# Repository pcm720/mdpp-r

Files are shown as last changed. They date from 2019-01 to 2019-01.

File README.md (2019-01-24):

## MegaDrive++ R

**MegaDrive++ R** is a modchip for the **Sega Mega Drive/Genesis** heavily inspired by [MegaDrive++ project](https://github.com/SukkoPera/MegaDrivePlusPlus/).
It uses cheap ATmega88PA microcontroller, [cheap PCB](https://oshpark.com/shared_projects/NskgzQ7B) and supports following features:
- **Region switching**: allows user to switch regions with a button combination on Player 1 controller or Reset button.
  - Hold **Left + Start + A** for two seconds to change region to USA, **Left + Start + B** to change region to Europe, and **Left + Start + C** to change region to Japan.
  - Hold **Right** instead of **Left** to change region **and** reset the console.
  - Hold **Left + Start + A + B + C** to save current region to memory and use it as default every time you turn on your console.
  - Hold the **Reset** button for more than four seconds to cycle through modes. This will reset the console.
  - Button combos can be customized in common.h.
- **In-game Reset**: hold **Start + A + B + C** to reset the console.
- Dual-frequency oscillator support: PCB has a special pin for DFO control.
- Unlike [MegaDrive++](https://github.com/SukkoPera/MegaDrivePlusPlus/), it doesn't support reset level autosensing, so to use it on boards with active-high reset signal you'll need to comment out a line in common.h. Note that this is untested: I don't own any consoles with active-high reset.
- Suggested PCB layout is optimized for Model 2 VA1 board.

Visit [wiki](https://github.com/pcm720/mdpp-r/wiki) for installation diagram for Model 2 VA1 board.

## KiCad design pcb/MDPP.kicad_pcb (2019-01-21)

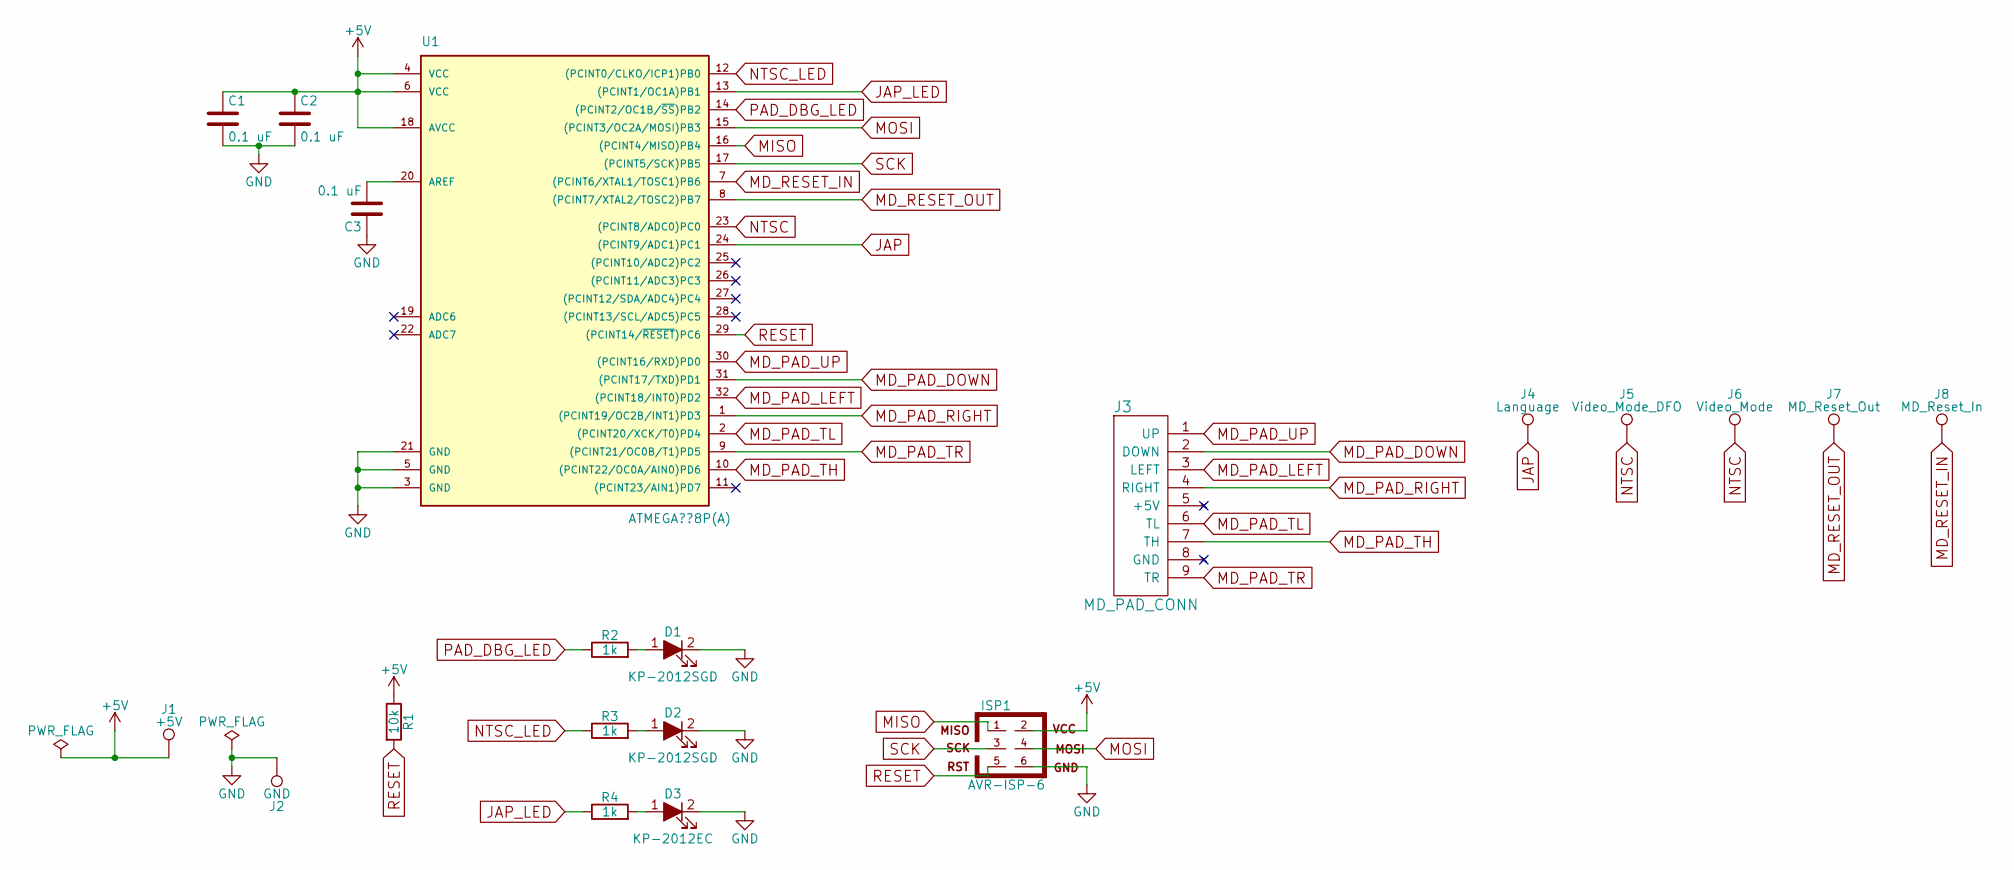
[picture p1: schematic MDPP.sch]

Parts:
D1, D2: KP-2012SGD
D3: KP-2012EC; KP-2012SGD
ISP1: AVR-ISP-6; AVR-ISP-6-SMD
J1: +5V; Soldering_Point_1.5x3mm
J2: GND; Soldering_Point_1.5x3mm
J3: MD_PAD_CONN
J4: Language; Soldering_Point_1.5x3mm
J5: Video_Mode_DFO; Soldering_Point_1.5x3mm
J6: Video_Mode; Soldering_Point_1.5x3mm
J7: MD_Reset_Out; Soldering_Point_1.5x3mm
J8: MD_Reset_In; Soldering_Point_1.5x3mm
R1: 10k; R_0805_HandSoldering
R2, R3, R4: 1k; C_0805
U1: ATMEGA??8P(A); TQFP-32_7x7mm_Pitch0.8mm
С1, С2, С3: 0.1 uF; C_0603_HandSoldering

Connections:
+5V: ISP1.2, J1.1, R1.1, U1.4 (VCC), U1.6 (VCC), U1.18 (AVCC), С1.1, С2.1
GND: D1.2 (A), D2.2 (A), D3.2 (A), ISP1.6, J2.1, U1.3 (GND), U1.5 (GND), U1.21 (GND), С1.2, С2.2, С3.1
JAP: J4.1, U1.24 ((PCINT9/ADC1)PC1)
JAP_LED: R4.1, U1.13 ((PCINT1/OC1A)PB1)
MD_PAD_DOWN: J3.2 (DOWN), U1.31 ((PCINT17/TXD)PD1)
MD_PAD_LEFT: J3.3 (LEFT), U1.32 ((PCINT18/INT0)PD2)
MD_PAD_RIGHT: J3.4 (RIGHT), U1.1 ((PCINT19/OC2B/INT1)PD3)
MD_PAD_TH: J3.7 (TH), U1.10 ((PCINT22/OC0A/AIN0)PD6)
MD_PAD_TL: J3.6 (TL), U1.2 ((PCINT20/XCK/T0)PD4)
MD_PAD_TR: J3.9 (TR), U1.9 ((PCINT21/OC0B/T1)PD5)
MD_PAD_UP: J3.1 (UP), U1.30 ((PCINT16/RXD)PD0)
MD_RESET_IN: J8.1, U1.7 ((PCINT6/XTAL1/TOSC1)PB6)
MD_RESET_OUT: J7.1, U1.8 ((PCINT7/XTAL2/TOSC2)PB7)
MISO: ISP1.1, U1.16 ((PCINT4/MISO)PB4)
MOSI: ISP1.4, U1.15 ((PCINT3/OC2A/MOSI)PB3)
NTSC: J5.1, J6.1, U1.23 ((PCINT8/ADC0)PC0)
NTSC_LED: R3.1, U1.12 ((PCINT0/CLKO/ICP1)PB0)
unnamed: D1.1 (K), R2.2
unnamed: D2.1 (K), R3.2
unnamed: D3.1 (K), R4.2
unnamed: U1.20 (AREF), С3.2
PAD_DBG_LED: R2.1, U1.14 ((PCINT2/OC1B/~SS~)PB2)
RESET: ISP1.5, R1.2, U1.29 ((PCINT14/~RESET~)PC6)
SCK: ISP1.3, U1.17 ((PCINT5/SCK)PB5)

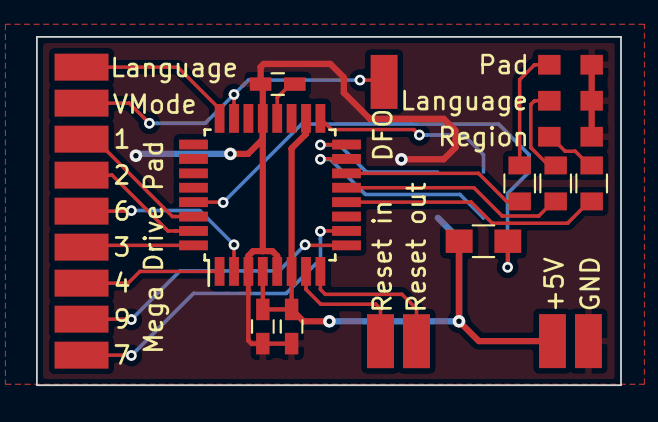
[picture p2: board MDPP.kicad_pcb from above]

Board: 2 copper layers, 32.4 x 19.3 mm, 20 parts (1 on the bottom side), 24 nets.

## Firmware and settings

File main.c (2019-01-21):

/*
MegaDrive++ R code for ATmega88PA
    Copyright (C) 2018-2019 pcm720 <pcm720@gmail.com>

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
    You should have received a copy of the GNU General Public License
    along with this program.  If not, see 
<http://www.gnu.org/licenses/>.
*/

#include "common.h"
#include <avr/interrupt.h>
#include "eeprom.h"
#include "control.h"

void init();
uint8_t parse_buttons(uint8_t buttons, uint8_t * action_flag);
void reset_loop();

volatile uint8_t read_status;
volatile uint8_t button_status;
volatile uint8_t timer_ticks;

int main() {
    init();

    uint8_t active_combo = COMBO_OFF;
    uint8_t parsed_combo = COMBO_OFF;
    uint8_t action_flag = 0x0; // Bits 0-1 — region (as in console_set_region), bits 4-7 — 0xF if reset is required, 0x0 if not

    while(1) {
        // Handle RESET button presses
        if (PINB_RESET & (1 << PB7)) {                 // If RESET button is pressed
            PCICR &= ~(1 << PCIE2);                    // Disable PCINT2
            TCCR1B &= ~(1 << CS12);                    // Disable timer in case it was running
            timer_ticks = 0;                           // Clear ticks
            _delay_ms(20);                             // Debounce delay
            if (PINB_RESET & (1 << PB7)) reset_loop(); // If button is still pressed, enter reset loop
            PCICR |= (1 << PCIE2);                     // Re-enable PCINT2
        }

        // Handle pad inputs
        if (read_status == 0xFF) {                     // If we received valid input during PCINT
            parsed_combo = parse_buttons(button_status, &action_flag);
            if (parsed_combo != active_combo) {        // If combo changed
                active_combo = parsed_combo;
                TCCR1B &= ~(1 << CS12);                // Disable timer
                timer_ticks = 0;                       // Clear ticks
                if (parsed_combo != COMBO_OFF) {
                    TCNT1 = 0;                         // Reset TC1
                    TCCR1B |=  (1 << CS12);            // Enable timer
                }
            } else if (timer_ticks > LENGTH_COMBO) {   // If valid combo was held for LENGTH_COMBO seconds
                TCCR1B &= ~(1 << CS12);                // Disable timer
                timer_ticks = 0;                       // Clear ticks
                if (active_combo == COMBO_RESET) console_reset();                 // Reset the console
                else if (active_combo == COMBO_SAVE) eeprom_write(PORTC & 0x3);   // Save current region to EEPROM
                else console_set_region((action_flag & 0xF), (action_flag & 0xF0));       // Set region accordingly
                active_combo = COMBO_OFF;              // Reset combo state
            }
        }
    }
}

void init() {
    // Enable pull-ups on unused pins:
    PORTB = 0x78;             // 01111000
    PORTC = 0xFC;             // 11111100
    PORTD = 0x83;             // 10000011
    // Set directions:
    DDRB = 0x7;               // 00000111 — pins PB2-0 are outputs
    DDRC = 0x3;               // 00000011 — pins PC0 and PC1 are outputs
    DDRD = 0x0;               // Set PORTD to input
    PRR = 0xE7;               // Enable power reduction

    uint8_t temp_region;
    if (eeprom_read(&temp_region)) {  // Read region from EEPROM
        temp_region = DEFAULT_REGION; // If reading failed, revert to default parameters
        eeprom_write(temp_region);    // Try to save defaults
    }
    console_set_region(temp_region,0x0);

    PCMSK2 |= (1 << PCINT22); // Enable PCINT on PD6 (Select)

    // Setup timers for reset button and combo button
    TCCR1B |= (1 << WGM12);   // Set up T/C1 to generate an interrupt every 1 s
    TIMSK1 |= (1 << OCIE1A);
    OCR1A = 31249;            // 31249 ticks ≈ 1 s

    console_reset();

    _delay_ms(20);            // Wait for the console to stabilize

    PCICR |= (1 << PCIE2);    // Enable PCINT2
    sei();
}

uint8_t parse_buttons(uint8_t buttons, uint8_t* action_flag) {
    switch (buttons) {
        case COMBO_RESET:
            *action_flag = 0x0;
            return COMBO_RESET;
        case COMBO_SAVE:
            *action_flag = 0x0;
            return COMBO_SAVE;
        case COMBO_USA:
            *action_flag = USA;
            return COMBO_USA;
        case COMBO_JAP:
            *action_flag = JAP;
            return COMBO_JAP;
        case COMBO_EUR:
            *action_flag = EUR;
            return COMBO_EUR;
        case COMBO_USA_RESET:
            *action_flag = (0xF0 | USA);
            return COMBO_USA_RESET;
        case COMBO_JAP_RESET:
            *action_flag = (0xF0 | JAP);
            return COMBO_JAP_RESET;
        case COMBO_EUR_RESET:
            *action_flag = (0xF0 | EUR);
            return COMBO_EUR_RESET;
        default:
            *action_flag = 0x0;
            return COMBO_OFF;
    }
}

void reset_loop() {
    TCNT1 = 0;              // Reset TC1
    TCCR1B |=  (1 << CS12); // Set the clock source to Clk/256 (enable timer)
    while (1) {
        _delay_ms(100);     // Wait
        // Break if RESET button was released or timer has ticked more than LENGTH_RESET times
        if (!(PINB_RESET & (1 << PB7)) || (timer_ticks > LENGTH_RESET)) break; 
    }
    TCCR1B &= ~(1 << CS12); // Disable timer
    if (timer_ticks > LENGTH_RESET) console_set_region(NXT,0x1);
    timer_ticks = 0;
}

// Interrupt vectors

// Detected level change on SELECT line:
ISR(PCINT2_vect) {
    // State 0:       * / C B R L D U (apply mask 00111111/0x3F)
    // State 1:       * / S A * * D U (apply mask 00110000/0x30 and shift to the left two times)
    // buttons_status map: A S B C R L D U
    uint8_t input = PIND;                   // Read pins on PORTD
    uint8_t int_button_status;              // To skip accessing volatile variable everytime we write here.
    // int_button_status is unintialized because GCC will generate more push instructions in the beginning of interrupt vector if variable is initialized here
    // That will cause additional delays, and we don't need that.
    
    read_status = 0x0;
    if (input & (1 << PD6)) {               // If select is high (PD6), this is state 0
        int_button_status = (input & 0x3F); // Save buttons (state 0)
        read_status = 0x0F;                 // Write 0x0F to status variable to indicate that state 0 has been read
    } else {                                // State 1
        int_button_status = ((input & 0x30) << 2); // To "initialize variable" in this branch
        if (!(input & 0xC)) {               // Check that LEFT and RIGHT are LOW before setting read status
            read_status = 0xF0;             // Write 0xF0 to status variable to indicate that state 1 has been read
        }
    }
    _delay_ms(1);                           // Wait until six-button reads are over. It's okay to delay here since we won't be doing anything during the read routine anyway
    input = PIND;                           // Read the other state
    if ((input & (1 << PD6)) && (read_status != 0x0F)) {
        int_button_status |= (input & 0x3F);
        read_status |= 0x0F;
    } else if (read_status != 0xF0) {
        if (!(input & 0xC)) {
            int_button_status |= ((input & 0x30) << 2);
            read_status |= 0xF0;
        }
    }

    if (read_status != 0xFF) read_status = 0x0; // Clear read status: the read was unsuccessful
    else button_status = int_button_status;
}

// Increase tick variable on timer-generated interrupt:
ISR(TIMER1_COMPA_vect) {
    timer_ticks++;
}

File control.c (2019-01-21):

/*
Console control functions
    Copyright (C) 2018-2019 pcm720 <pcm720@gmail.com>

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
    You should have received a copy of the GNU General Public License
    along with this program.  If not, see 
<http://www.gnu.org/licenses/>.
*/

#include "control.h"
#include <util/atomic.h>

void console_set_region(uint8_t region, uint8_t reset) {
    ATOMIC_BLOCK (ATOMIC_RESTORESTATE) {
        if (reset && !(PINB_RESET & (1 << PB7))) { // Assert WRES if reset is required and WRES is not pulled by user
            #ifdef RESET_ACTIVE_LOW
                DDRB |= (1 << PB7);
            #else
                PORTB |= (1 << PB7);
                DDRB |= (1 << PB7);
            #endif
            PORTB |= (1 << PB2);   // Turn on PAD_DBG_LED
        }
        if (region == NXT) {       // If next region is selected
            switch (PORTC & 0x3) { // Read current region from PORTC by clearing everything except PC0 and PC1
                case USA:          // Set region variable to next region
                    region = EUR;
                    break;
                case JAP:
                    region = USA;
                    break;
                case EUR:
                    region = JAP;
                    break;
                default:
                    region = DEFAULT_REGION;
                    break;
            }
        }
        PORTC = (PORTC & ~(0x3)) | region; // Set region by reading current value of PORTC, clearing PC0 and PC1 and adding region variable
        PORTB = (PORTB & ~(0x3)) | region; // Same, but with LEDs
        if (reset) {                       
            _delay_ms(350);                // Release WRES after 350 ms
            PORTB &= ~(1 << PB2);          // Turn off PAD_DBG_LED
            #ifdef RESET_ACTIVE_LOW
                DDRB &= ~(1 << PB7);
            #else
                DDRB &= ~(1 << PB7);
                PORTB &= ~(1 << PB7);
            #endif
        }
    }
}

void console_reset() {
    ATOMIC_BLOCK (ATOMIC_RESTORESTATE) {
        #ifdef RESET_ACTIVE_LOW
            DDRB |= (1 << PB7);   // Pull WRES down
        #else
            PORTB |= (1 << PB7);  // Pull WRES up
            DDRB |= (1 << PB7);   // Change direction to output
        #endif
        PORTB |= (1 << PB2);      // Turn on PAD_DBG_LED
        _delay_ms(350);
        PORTB &= ~(1 << PB2);     // Turn off PAD_DBG_LED
        #ifdef RESET_ACTIVE_LOW
            DDRB &= ~(1 << PB7);  // Release WRES
        #else
            DDRB &= ~(1 << PB7);  // Change direction to input
            PORTB &= ~(1 << PB7); // Release WRES
        #endif
    }
}

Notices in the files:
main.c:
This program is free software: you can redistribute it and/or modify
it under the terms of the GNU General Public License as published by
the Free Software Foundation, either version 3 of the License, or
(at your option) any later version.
